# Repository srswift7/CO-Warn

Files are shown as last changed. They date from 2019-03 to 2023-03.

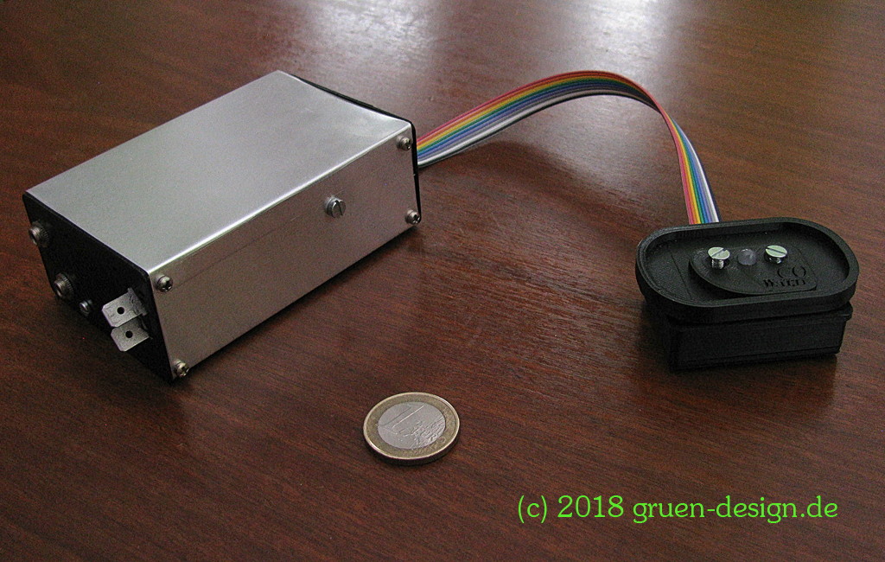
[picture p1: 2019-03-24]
IMG_3259.jpg

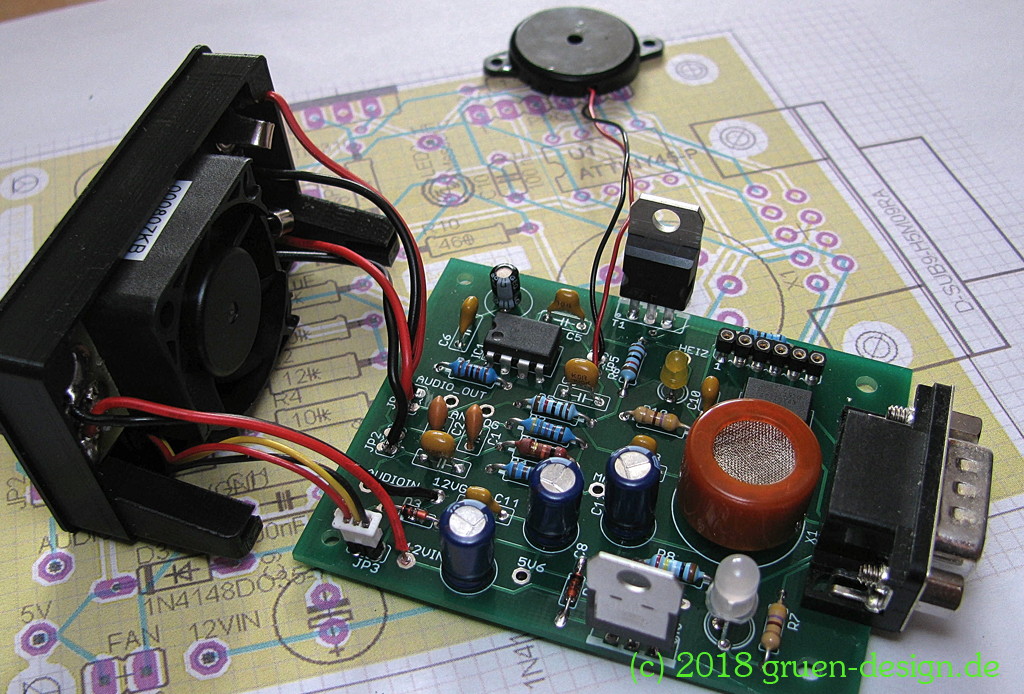
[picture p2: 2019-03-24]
IMG_3249.jpg

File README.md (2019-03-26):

Again and again, accident reports on the dangers of CO haunt the news. For example in aviation. The crash of the famous Aerobatics W.Dallach was then the initial spark. So a small CO sensor should not be too complicated, right?

MQ-7 is the name of the game, first of all, it is important to understand how the CO sensor works.

How does such a gas sensor work? The heart is a metal plate
made of a special alloy. At a well-defined temperature
somewhere beyond 200 ° C, gas molecules attach to the surface
and change the electrical resistance. That can then be measured.
Which gas molecules is determined by material and temperature. For the
correct temperature ensures a built-in heating.

The MQ-7 sensor is available on a small circuit board with some
Built-in components, the manufacturer calls the whole gadget "Flying Fish",
for whatever reason. The circuit evaluates the resistance and switches
at an adjustable threshold a light emitting diode. Dimensions,
Operating voltage and one analog and one digital output.

The data sheet of the MQ-7 sensor, on the other hand, raises a few questions. It
gives a cycle of 60 seconds heating with 5V without measuring (it will
practically the sensor "cleaned") and then 90 seconds heating with 1.4V
(during this time can be measured) before. The "Flying Fish" doesn't run such a complicated scenario. I doubt thet the "Flying Fish" is usable for practical CO detection at all.

A ATtiny is able to control the measurement using a plain MQ-7 sensor following the usage sequence below:

1.) preheat. The sensor is set to the default heating voltage (5.0V) for 90 seconds. LED lights up yellow.

2.) Calibration. The specified (datasheet)  heating / measuring cycle is run once, the resistance values are stored at fixed intervals. This will then be used in later operation as "characteristic". LED lights up green

3.) Operation. The specified heating / measuring cycle is run. The measured values are stored and compared with the "characteristic curve". Deviations are detected and reported according to their size and duration. LED flashes green briefly in a long interval. (Everything OK) or red (deviation from the characteristic found). In the event of deviations above a limit value or an absolute value (according to the characteristic from the data sheet), the LED flashes / lights up red and a warning tone sounds in the headset.

The sensitivity of the circuit is impressive. One lit tea light next to the sensor box is registered.

So, the CO-Warner has been in practical use for a year now in a Skyranger LSA. It has not found CO yet, but gasoline fumes. At a
Overland flight, the device suddenly began to warn. A carburetor gasket had a crack. Fixed, and no warnings any more.

Hardware:

IC2 is the usual 7805. The on-board voltage is nominally 12V, but ever of course this is something between 11.x and 14.x according to load / state of charge Volt. Through the diode D1, the fixed voltage regulator is on output voltage of 5.6..5.7 V pimped. That's me back out the heater voltage can switch from the sensor via transistor T1 and in heating case also arrive 5V. The 1.4V heating voltage during the measuring phase is controlled by the Attiny with PWM. The exact values of the PWM constants have been found by experiment and voltmeter.

The LED2 is actually only required for the experimental phase and indicates whether the sensor is currently being heated or measured.

SV1 is the usual 6-pin programming plug. The same pins are also connected to the 9-pin SUB connector. So the Attiny can be accessed (flashed, data read) from "outside". There are some more sensor voltage pins for diagnostic purposes.

LED1 is the already mentioned bicolour LED. The different serial resistors ensure that in the case of "both on" really yellow
arrives and and no kind of orange. The two R and the diode is natural required only once, either on the PCB or externally behind the SUB-D plug.

The Attiny gets its supply voltage via the D3, that's it again 5V.

PB4 is connected as a voltmeter and with the corresponding sensor pin connected.

IC1 is a 386, it mixes an external signal source (warning signal from FLARM) with a warning sound from the PB3 and puts the whole as an audio signal ready for the intercom.

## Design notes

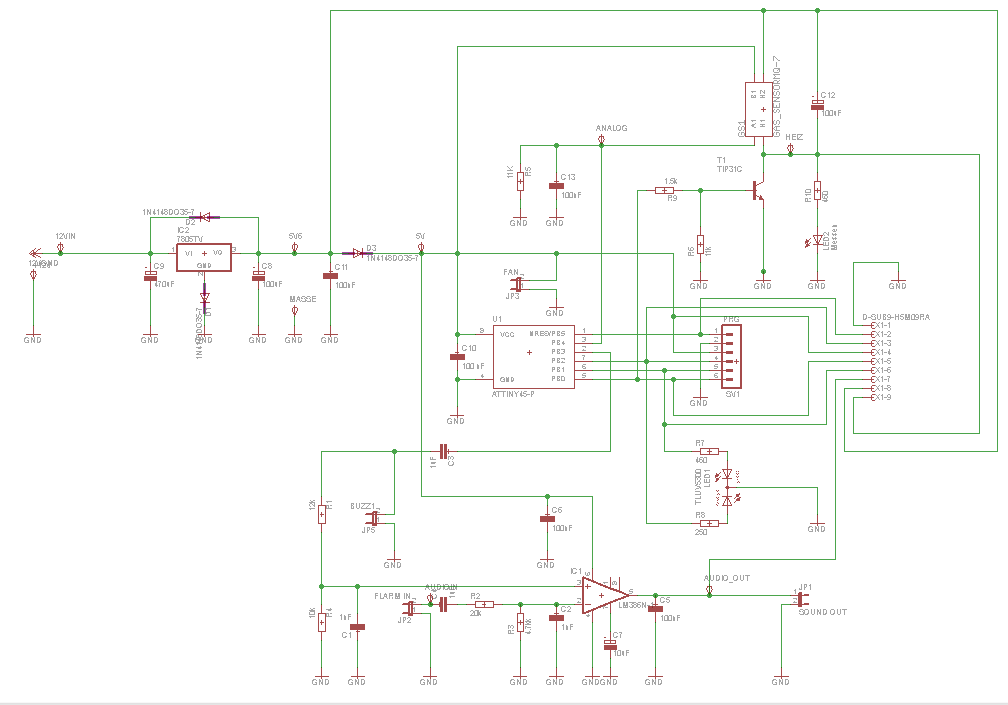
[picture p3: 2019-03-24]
Hardware/CO-Warn-v2.png

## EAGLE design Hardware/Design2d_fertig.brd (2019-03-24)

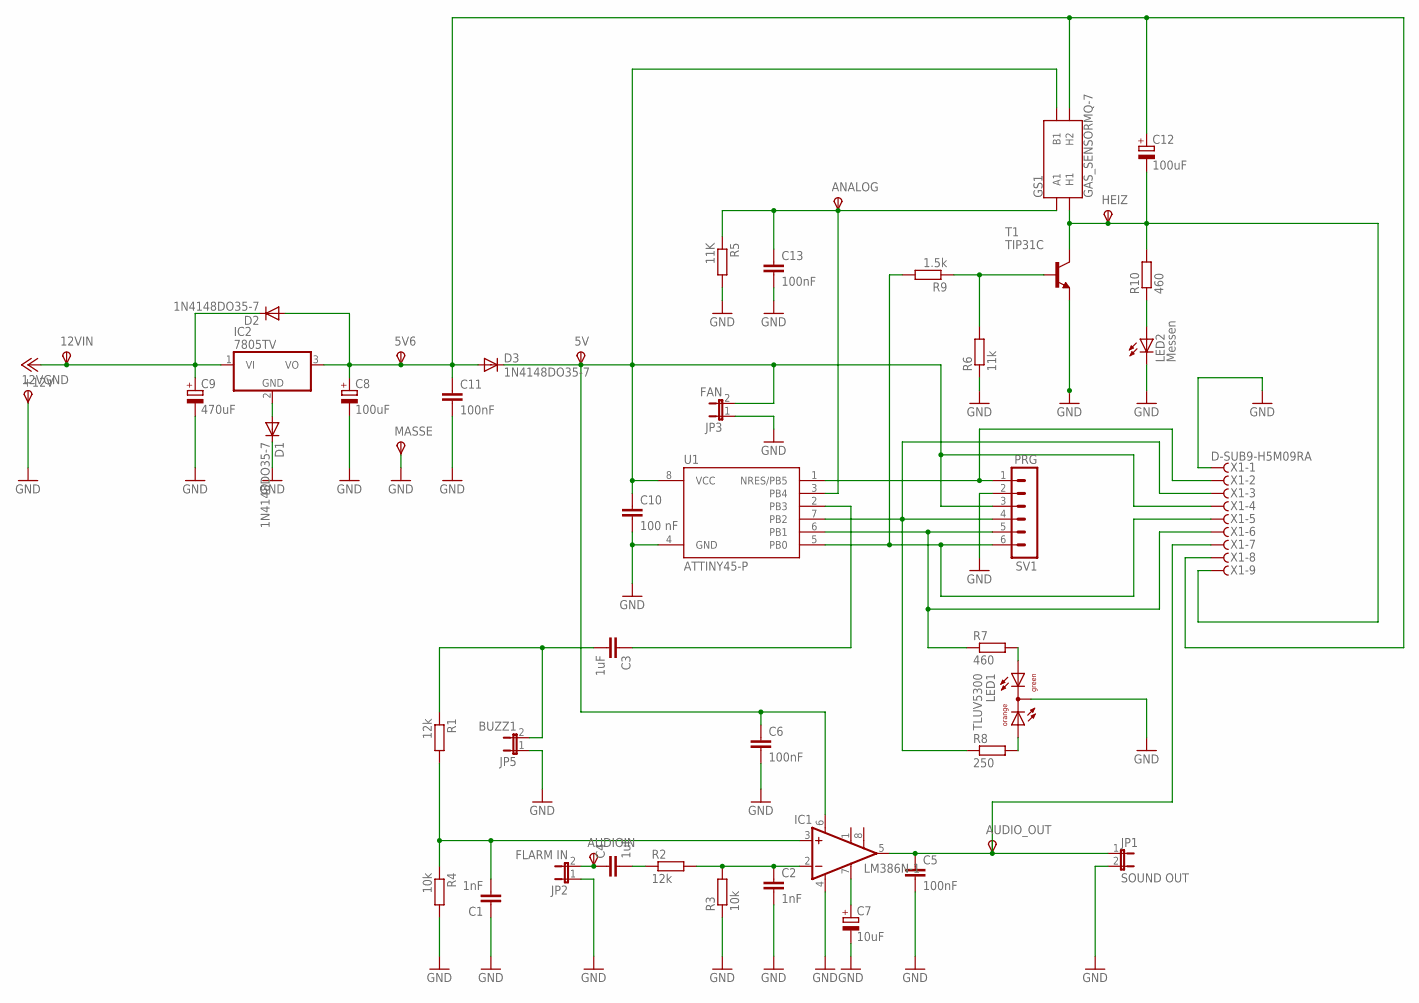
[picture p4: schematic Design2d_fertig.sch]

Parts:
5V, 5V6, 12VGND, 12VIN: TPSPAD1-13; P1-13
ANALOG: TPSPAD1-13; P1-13
AUDIOIN: TPSPAD1-13; P1-13
AUDIO_OUT: TPSPAD1-13; P1-13
C1, C2: 1nF; C025-030X050
C3, C4: 1uF; C050-025X075
C5, C6, C11, C13: 100nF; C050-025X075
C7: 10uF; E2,5-7
C8, C12: 100uF; E2,5-7
C9: 470uF; E2,5-7
C10: 100 nF; C050-024X044
D1, D2, D3: 1N4148DO35-7; DO35-7
GS1: GAS_SENSORMQ-7; GAS_SENSOR
HEIZ: TPSPAD1-13; P1-13
IC1: LM386N-1; DIL08
IC2: 7805TV; TO220V
JP1: SOUND OUT; JP1
JP2: FLARM IN; JP1
JP3: FAN; JP1
JP5: BUZZ1; JP1
LED1: TLUV5300
LED2: Messen; LED3MM
MASSE: TPSPAD1-13; P1-13
R1, R2: 12k; 0207/10
R3, R4: 10k; 0207/10
R5: 11K; 0207/10
R6: 11k; 0207/10
R7, R10: 460; 0207/10
R8: 250; 0207/10
R9: 1.5k; 0207/10
SV1: PRG; MA06-1
T1: TIP31C; TO220V
U1: ATTINY45-P; PDIP08_300MIL
X1: D-SUB9-H5M09RA; H5M09RA

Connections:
5.6V: 5V6.TP, C8.+, C11.1, C12.+, D2.A, D3.A, GS1.HB (H2), IC2.3 (VO), X1.8
5V: 5V.TP, C6.1, C10.1, D3.C, GS1.B1, IC1.6 (VS), JP3.2, SV1.3, U1.8 (VCC), X1.4
+12V: 12VIN.TP, C9.+, D2.C, IC2.1 (VI)
AUDIO: AUDIO_OUT.TP, C5.1, IC1.5 (OUT), JP1.1, X1.7
GND: 12VGND.TP, C1.1, C2.2, C5.2, C6.2, C7.-, C8.-, C9.-, C10.2, C11.2, C13.2, D1.C, IC1.4 (GND), JP1.2, JP2.1, JP3.1, JP5.1, LED1.CC, LED2.K (C), MASSE.TP, R3.1, R4.2, R5.2, R6.1, SV1.2, T1.3 (E), U1.4 (GND), X1.1
HEIZ: C12.-, GS1.HA (H1), HEIZ.TP, R10.2, T1.2 (C), X1.9
unnamed: C3.2, JP5.2, R1.1
unnamed: C1.2, IC1.3 (+IN), R1.2, R4.1
unnamed: C2.1, IC1.2 (-IN), R2.2, R3.2
unnamed: SV1.1, U1.1 (NRES/PB5), X1.2
unnamed: C4.2, R2.1
unnamed: R7.1, SV1.5, U1.6 (PB1), X1.6
unnamed: C7.+, IC1.7 (BYPASS)
unnamed: LED1.AG, R7.2
unnamed: LED1.AO, R8.2
unnamed: R8.1, SV1.4, U1.7 (PB2), X1.3
unnamed: C3.1, U1.2 (PB3)
unnamed: D1.A, IC2.2 (GND)
unnamed: R9.2, SV1.6, U1.5 (PB0), X1.5
unnamed: ANALOG.TP, C13.1, GS1.A1, R5.1, U1.3 (PB4)
unnamed: AUDIOIN.TP, C4.1, JP2.2
unnamed: R6.2, R9.1, T1.1 (B)
unnamed: LED2.A, R10.1

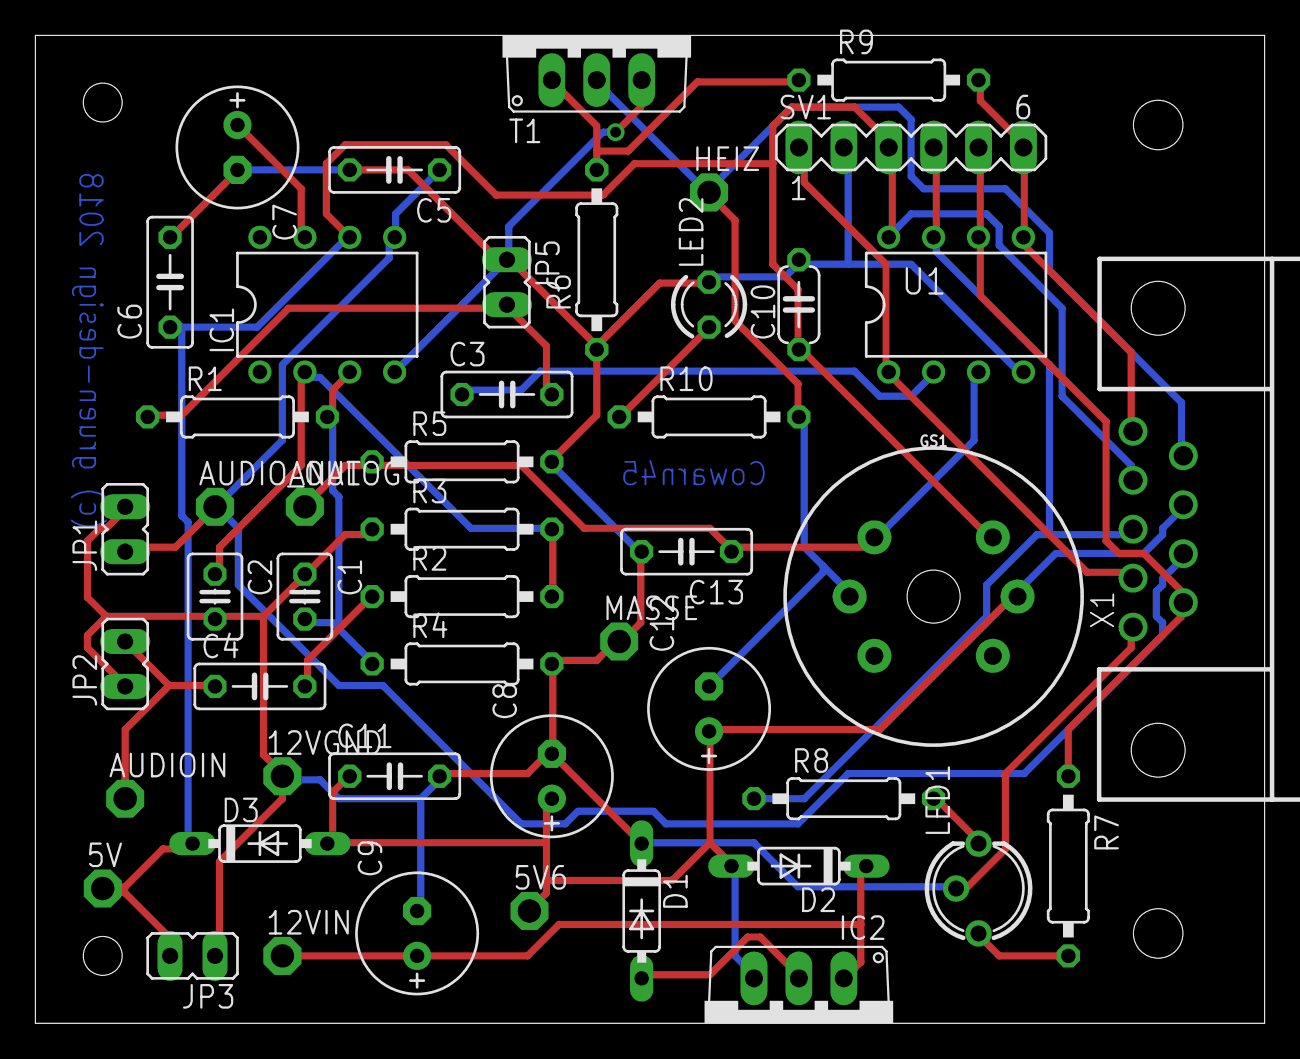
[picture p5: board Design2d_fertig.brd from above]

Board: 2 copper layers, 69.5 x 55.9 mm, 48 parts (0 on the bottom side), 23 nets.

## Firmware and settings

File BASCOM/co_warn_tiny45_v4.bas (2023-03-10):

'----------------------------------------------------------
'
' Software fuer den CO-Warner mit MQ-7
'
' (c) 2018-2020 gruen-design.de
'
' V11.0b
'
' Feinere Messaufloesung
' Glaettung der Messwerte, wir vergleichen mit dem Mittelw der letzten 3 Messungen
' Messungen alle 2 Sekunden
' Auswertefenster zwischen nur in der Messphase
' Intelligentere Beep-Steuerung
' Protokollierung der Messung im EEPROM
'
'----------------------------------------------------------

$prog &HFF , &HE2 , &HDF , &HFF                             ' generated. Take care that the chip supports all fuse bytes.

$regfile = "Attiny45.dat"                                   'ATtiny45-Deklarationen
$crystal = 8000000                                          'No Quarz: 8 MHz

$hwstack = 64                                               ' default use 32 for the hardware stack
$swstack = 64                                               ' default use 10 for the SW stack
$framesize = 96                                             ' default use 40 for the frame space

Declare Sub Beep(byval Dauer As Integer)                    ' Eine Tonausgabe auf PORTB.3
Declare Function Messme() As Byte                           ' Messen am ADC,

Dim Spann As Byte
Dim Bctr As Integer

Dim Mwert As Byte
Dim Memptr As Byte                                          ' Attiny45 hat nur 256 EEPROM Zellen

Dim Z As Integer                                            ' Zaehler fuer den Timer 1,
Dim Testloop As Byte

Dim Kalibrieren As Bit

Dim Iind As Integer
Dim Vergleich As Integer

Dim Sum As Integer

Dim Alarmctr As Byte                                        ' Zaehler, Ob Wir Schon Einen Alarm Hatten , Damit Wir Nicht In Ein Dauerbeep Verfallen

Dim Messdat(256) As Eram Byte

Dim Messf(3) As Integer                                     ' Zwischenspeicher fuer die letzten 3 Messungen

' ======================================
' Einstellwerte
' ======================================

Const Messtoleranz = 5

' Beta
' Osccal = 117                                                ' Kalibrierung des RC Oscillators, Dieser Wert muss hinexperimentiert werden
' Const 5volt = 79
' Const 14volt = 210                                          ' 206 = 1.264

' Prod!
Osccal = 85                                                 ' Kalibrierung des RC Oscillators, Dieser Wert muss hinexperimentiert werden
Const 5volt = 60
Const 14volt = 206                                          ' 206 = 1.264

Ddrb = &B00001111                                           'PB0-3 Ausgang, ...PB4..: Eingang

' HIer das gleich noch mal einzeln
' Ddrb.0 = 1                     ' PWM
' Ddrb.1 = 1                     ' rot
' Ddrb.2 = 1                     ' gruen
' Ddrb.3 = 1                     ' Beep


' Timer0 verwenden wir als PWM für die 5V/1.4V
' Das ganze kommt dann am B0 an (Pin5)
Config Timer0 = Pwm , Prescale = 1 , Compare A Pwm = Clear Down

'
' Tccr0a = &B10000001                                         'Pin OC1A nicht invertiert, 8-Bit-
' Tccr0b = &B00000010                                         '...PWM phasenkorrekt, Timer1 1/8


' Definitionen fuer den AD-Wandler an B4 (Pin3)
'----------------------------------------------------------

' Admux = &B01100010                                          'Bits7+6=01: Aref ist intern verbunden
'                      'Bit5=1: LeftAdjust, nur 8 Bit in ADCH
'                     'Bits1...0=0010: Pin ADB4 als Input  wählen

Admux = &B00110010

' Adcsra = &B11100010                                         'Bit7=1:AdcOn,Bit6=1:Start,Bit5=1:Frei
'                      'Bits2+1+0=010: AdcClock=AvrClock/4

Adcsra = &B11100100                                         ' Takt / 16


' Vorwaermen ohne Messen - Ein kompletter Zyklus 60+90 Sekunden

Compare0a = 5volt

Waitms 1000

' Test der LED
' Rot
Portb.1 = 1
Portb.2 = 0

Waitms 300

' Gruen
Portb.1 = 0
Portb.2 = 1

Waitms 300

'  1 Minute Heizspannung

' LED Rot
Portb.1 = 1
Portb.2 = 0

' Portb.3 = 1
Call Beep(100)

Wait 60

'  90 Sekunden Messspannung

' Gruen + Rot = GELB
Portb.1 = 1
Portb.2 = 1
Compare0a = 14volt

Wait 90

' Bereit zur Arbeit!

Kalibrieren = 1
Z = 0
Testloop = 0
Memptr = 0
Alarmctr = 0
Vergleich = 0

' Messfeld zuruecksetzen
Messf(1) = 0
Messf(2) = Adch
Waitms 100
Messf(3) = Adch


' Portb.3 = 0
Portb.1 = 0                                                 ' LED aus
Portb.2 = 0
Compare0a = 5volt


' Die Basis ist ein 1s Grundtakt,
' Dazu braucen wir einen Timer1

' 8MHZ mit prescale 1024 ergibt 7812 Ticks,
' das sind 30 volle Durchläufe pro Sekunde

Config Timer1 = Timer , Prescale = 1024
Enable Timer1
Enable Interrupts

On Timer1 Timer2s

' Endlosschleife
Do                                                          'Hauptschleife
Loop


' Ende des Programms (falls es sowas ueberhaupt gibt)

' ####################################################
' # Unterprogramme und Funktionen
' ####################################################

' ####################################################
' Das hier ist der interrupt 30 mal in der Sekunde.
' ####################################################
Timer2s:

Incr Z                                                      ' Ein Nachteiler um auf die 2 Sekunden zu kommen
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

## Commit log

2019-03-24 Create readme
    Her I will store the ULTIMAKER files for the device
2019-10-08 Add files via upload
    G-Code for Ultimaker 2+ (PLA, 0.4 Nozzle)
2023-03-10 calibration of the absolute value
    * calibration of the absolute value
    * warning (red LED) starts around 30ppm, beep begins around 100ppm CO
    * small code cleanup
    * only 6 beeps in alarm case, after the heating period another max. 2 beeps are created if there was an alarm before the heating period

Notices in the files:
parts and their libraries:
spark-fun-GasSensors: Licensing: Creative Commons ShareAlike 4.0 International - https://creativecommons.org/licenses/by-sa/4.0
